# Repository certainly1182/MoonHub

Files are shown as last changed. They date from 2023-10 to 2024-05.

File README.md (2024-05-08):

# MoonHub - Unified Daughterboard-esque USB 2.0 Hub
This repository contains the hardware for a USB hub designed for mechanical keyboards.
Designed for use with the [MoonBoard](https://github.com/certainly1182/MoonBoard).

## Features
- USB-C input, 1x USB-C output, 2x USB-A output, 1x Molex EZMate.
- USB 2.0 high-speed with MTT for downstream ports.
- Overcurrent limit.
- ESD Protection.

## Images
top
bottom

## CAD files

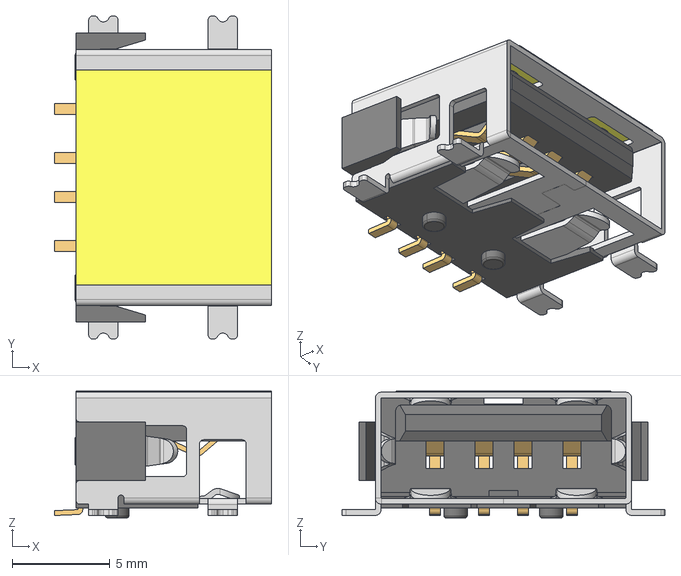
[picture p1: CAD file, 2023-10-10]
629104190121.stp
11.1 x 16.5 x 6.47 mm

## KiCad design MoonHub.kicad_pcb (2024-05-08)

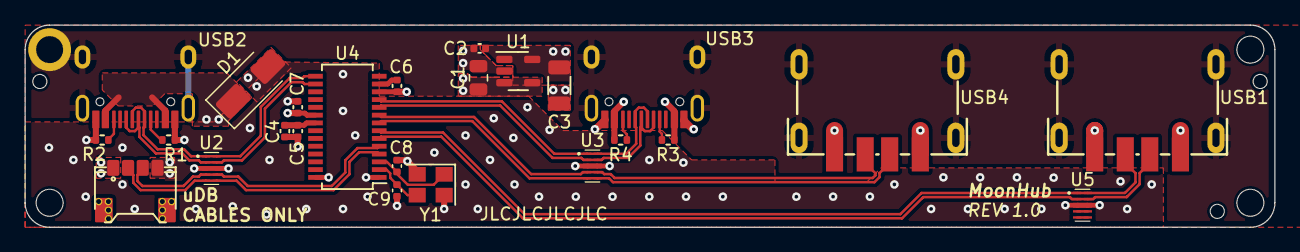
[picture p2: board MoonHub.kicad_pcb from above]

Board: 4 copper layers, 102.0 x 16.5 mm, 32 parts (0 on the bottom side), 22 nets.

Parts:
C1: 10u; C_0805_2012Metric
C2, C5: 100n; C_0402_1005Metric
C3: 100u; C_1206_3216Metric
C4: 10u; C_0402_1005Metric
C6, C7: 1u; C_0402_1005Metric
C8, C9: 20p; C_0402_1005Metric
D1: SMAJ5.0A; D_SMA
H1, H3, H4: MountingHole; MountingHole_2.2mm_M2_ISO7380
H2: MountingHole_Pad; Generic-Mounthole-Plated
H5, H6, H7: ToolingHole; JLC-Tooling-Hole
J1: X1224WRS-04-LPV01; UDB-PicoEZMate-Reinforced-Alt
R1, R2: 5k1; R_0402_1005Metric
R3, R4: 56k; R_0402_1005Metric
U1: AP22818AKBWT-7; SOT-23-5
U2, U3, U5: H5VU25U; DFN2510
U4: CH334U; SSOP-28_3.9x9.9mm_P0.635mm
USB1, USB4: USB_A; USB-A-SMD_USB-M-21_914-441A2021S10200
USB2, USB3: USB_C_Receptacle_USB2.0; HRO-TYPE-C-31-M-12-Assembly
Y1: 12MHz; Crystal_SMD_3225-4Pin_3.2x2.5mm

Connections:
+5V: C1.1, C7.1, D1.1 (A1), U1.3 (IN), U1.4 (EN), U4.20 (V5), USB2.A4 (VBUS), USB2.B4 (VBUS)
/USB1_D+: U3.1 (IO1), U3.10 (NC), U4.11 (DP1), USB3.A6 (D+), USB3.B6 (D+)
/USB1_D-: U3.2 (IO2), U3.9 (NC), U4.10 (DM1), USB3.A7 (D-), USB3.B7 (D-)
/USB2_D+: U3.4 (D2+), U3.7 (NC), U4.9 (DP2), USB4.3 (D+)
/USB2_D-: U3.5 (D2-), U3.6 (NC), U4.8 (DM2), USB4.2 (D-)
/USB3_D+: U4.7 (DP3), U5.1 (IO1), U5.10 (NC), USB1.3 (D+)
/USB3_D-: U4.6 (DM3), U5.2 (IO2), U5.9 (NC), USB1.2 (D-)
/USB4_D+: J1.3, U2.4 (D2+), U2.7 (NC), U4.5 (DP4)
/USB4_D-: J1.2, U2.5 (D2-), U2.6 (NC), U4.4 (DM4)
/USBU_D+: U2.2 (IO2), U2.9 (NC), U4.16 (DPU), USB2.A6 (D+), USB2.B6 (D+)
/USBU_D-: U2.1 (IO1), U2.10 (NC), U4.15 (DMU), USB2.A7 (D-), USB2.B7 (D-)
GND: C1.2, C2.2, C3.2, C4.2, C5.2, C6.2, C7.2, C8.2, C9.2, D1.2 (A2), J1.4, R1.2, R2.2, U1.2 (GND), U2.3 (GND), U2.8 (GND), U3.3 (GND), U3.8 (GND), U4.1 (GND), U4.12 (GND), U4.28 (GND), U5.3 (GND), U5.8 (GND), USB1.4 (GND), USB2.A1 (GND), USB2.B1 (GND), USB3.A1 (GND), USB3.B1 (GND), USB4.4 (GND), Y1.2, Y1.4
GNDPWR: H2.1, J1.MP (MountPin), USB1.5 (Shield), USB2.S1 (SHIELD), USB3.S1 (SHIELD), USB4.5 (Shield)
unnamed: C4.1, C5.1, U4.21 (VDD33)
unnamed: C6.1, U4.13 (VDD33)
unnamed: C8.1, U4.3 (XI), Y1.1
unnamed: C9.1, U4.2 (XO), Y1.3
unnamed: R1.1, USB2.A5 (CC1)
unnamed: R2.1, USB2.B5 (CC2)
unnamed: R3.2, USB3.A5 (CC1)
unnamed: R4.2, USB3.B5 (CC2)
VBUS: C2.1, C3.1, J1.1, R3.1, R4.1, U1.1 (OUT), U1.5 (OUT), USB1.1 (VBUS), USB3.A4 (VBUS), USB3.B4 (VBUS), USB4.1 (VBUS)

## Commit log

2023-09-04 second commmit
    [MoonHub.kicad_pcb]
2023-09-04 remove unused schematic
    [udb.kicad_sch]
2023-09-05 fully routed
    [MoonHub-CuBottom.gbr, MoonHub-CuIn1.gbr, MoonHub-CuIn2.gbr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]
2023-09-07 reroute for smaller size
    [MoonHub-CuBottom.gbr, MoonHub-CuIn1.gbr, MoonHub-CuIn2.gbr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]
2023-09-19 move uDB connector & switch current limit
    [MoonHub-CuBottom.gbr, MoonHub-CuIn1.gbr, MoonHub-CuIn2.gbr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]
2023-09-26 redo esd protection
    [MoonHub.kicad_pcb, MoonHub.kicad_sch]
2023-10-10 export step
    [629104190121.stp, MoonHub.kicad_pcb]
2023-10-18 change usb esd array
    [MoonHub.kicad_pcb, MoonHub.kicad_sch]
2024-01-21 remove ferrites
    [MoonHub-CuBottom.gbr, MoonHub-CuIn1.gbr, MoonHub-CuIn2.gbr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]
2024-02-18 change ESD
    [MoonHub-CuBottom.gbr, MoonHub-CuIn1.gbr, MoonHub-CuIn2.gbr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]
2024-05-08 update to KiCad 8
    [MoonHub.kicad_pcb, MoonHub.kicad_sch]
